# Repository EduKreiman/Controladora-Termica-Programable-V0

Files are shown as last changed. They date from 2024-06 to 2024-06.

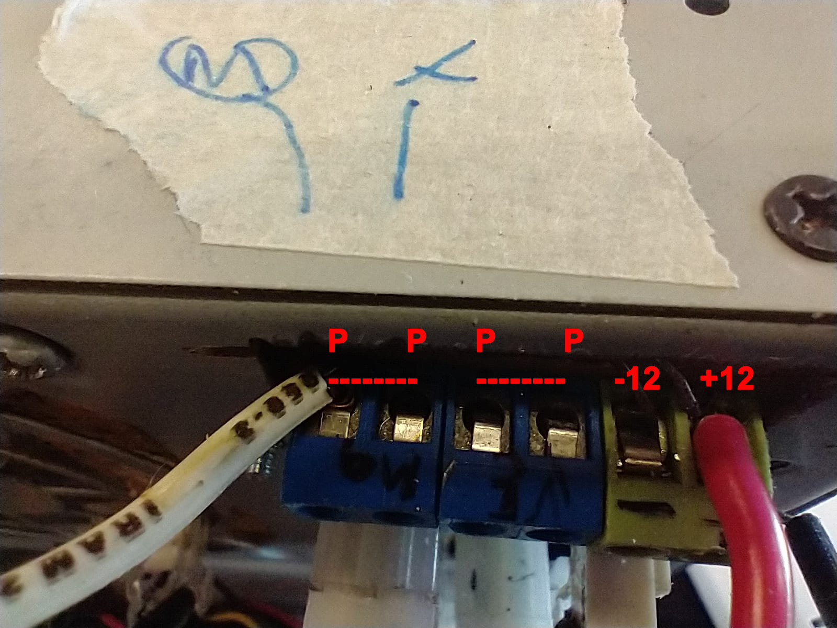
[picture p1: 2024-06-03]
Version03/hardware/conecciones bornera.jpg

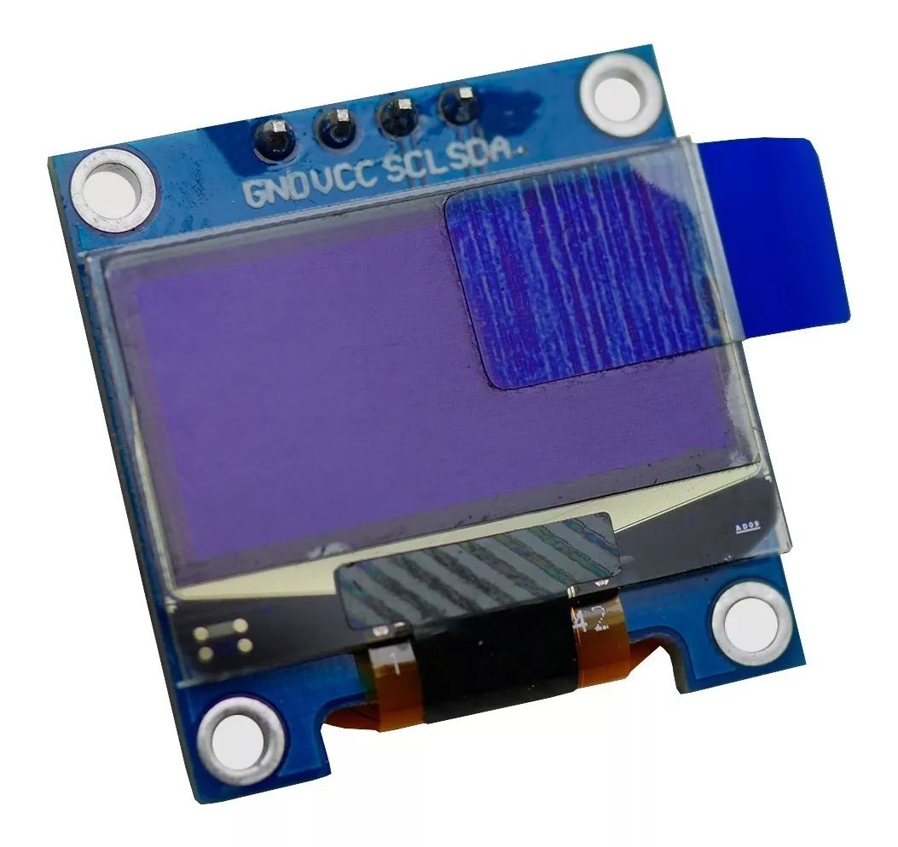
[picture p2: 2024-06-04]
Version03/hardware/display oled 1330 lado cristal.jpg

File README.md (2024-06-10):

En este repositorio se encuentran las descripciones de los circuitos necesarios para el ensamblado de una Controladora Térmica Programable (CTP), así como los scripts para su funcionamiento.

Las CTPs pueden ser utilizadas para dirigir ciclos térmicos diarios y el fotoperiodo dentro de una incubadora térmica, así como tambíen pueden establecer rampas térmicas para ensayos de temperatura crítica (CTmin y CTmax). Todas las funciones estan contenidas en un microcontrolador Arduino UNO.
Fueron construidas inicialmente para el Laboratorio de Ecofisiología de Insectos (IBBEA-CONICET-UBA), para experimentos con el objetivo de asestar el efecto fluctuación térmica sobre diferentes variables fisiológicas en insectos.

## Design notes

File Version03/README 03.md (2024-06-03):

VERSION 03 AUTONOMO-CONFIGURABLE OLED: El sistema esta contenido en un microcontrolador Arduino UNO. El funcionamiento es autónomo y continuo, repitiendo un programa termico seleccionado, entre los que están rampas térmicas ascendentes y descendentes, temperaturas constantes y el ciclo dirario de Parton&Logan, 1980. Asimismo controla simulación del ciclo de fotoperiodo diario cargando la hora de amanecer y anochecer en el sketch "parametror.ino"

La interfase de usuario consta de un display oled que junto con 3 pulsadores y un selector rotativo permiten a travez de menues sucesivos configurar todas las variables y seleccionar las rutinas termicas y el fotoperiodo.
  
Asimismo,un par de leds rojo y verde que indican el estado de enfriamiento o calentamiento respectivamente, y un tercer led que pulsa al ritmo de cada lectura de temperatura como indicador de funcionamiento correcto. La llave on/off de la fuente de alimentacion habilita el funcionamiento del equipo.

Un reloj interno (RTC), con batería de 10 años de duración, entrega el input para el cálculo de la ecuación para el ciclo diario. Esto le permite al sistema soportar interrupciones de alimentación, ya que el ciclo se reinicia en según la hora del reloj interno. Usa un sensor de temperatura Dallas Temperature (o Maxim Systems) Modelo 18b20, cuya lectura (Ti) es comparada con la temperatura de calculo para cada instante (Tcal). El signo de Ti-Tcal dispara la rutina frio/calor, activando la rama correspondiente del puente-H según la rutina seleccionada. El valor de ancho de pulso (PWM) que recibe el puente-H es función del módulo de Ti-Tcal, corregida por la rutina PID (Proporcional, Integral, Derivada).

Esta versión utiliza un puente H industrial de calidad automotriz con sistemas embebidos de proteccion termica e inversion de polaridad. 
se incluye en esta version un control de corriente / potencia entregada a la placa peltier para reducir el efecto Joule en la fase de enfriamiento. este se control se realiza con un modulo sensor de corriente por efecto Hall.

El control de la temperatura se logra a través de una placa peltier, tanto para el ciclo de calor como el ciclo de enfriamiento.

Referencias: Parton, W. J., & Logan, J. A. (1981). A model for diurnal variation in soil and air temperature. Agricultural Meteorology, 23, 205-216. https://doi.org/10.1016/0002-1571(81)90105-9

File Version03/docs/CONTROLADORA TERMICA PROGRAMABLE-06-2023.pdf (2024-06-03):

## CON

## Man

## Ope

1

0‐ Ini

Es

1‐ Set

2‐ Me

3‐ me

4‐ me

## NTROLADO

## nual de uso

## radores:

A | HUYE bo
B | ACEPTA‐
C | CAMBIA

Entra y Sale

Cambia dec

Cambia cícli

. Menúes o

icial: Siempre

ta pantalla m

teador: habilit

enú Modo/Pro

enú Temp | :
enú Foto | :
| P

CONTROLA
Diseño

## ORA TERMI

o:

otón: cíclico p

la opción o

BOTÓN p

BOTÓN p

ROTOR cam

e ‐>A

cimales ‐>B pu

icamente Cam

pantallas:

se vuelve a e

uestra: Las te

ta el ingreso a

ogs: seleccion

Temp. c

Temp. L

Circadia

: parametriza

: simula el fot

Parametriza am

ADOR TERMIC
o y Service 11

## CA PROGR

para entrar y s

o el campo mo

pulso mayor d

pulso corto ava

mbia dígitos e

Cambia N

ulso de 1 Sg.

mpos ‐>B pul

sta Pantalla/M

mperaturas M

La tempera

La temper

La diferenc

La hora ac

a los siguiente

na Programas

constante (Ter

Lineal (y=mx+

ano (modelo

T1 y T2 (Tem

operiodo regu

manecer y ano

CO PROGRA
1‐5472‐5201

## RAMABLE

https://drive.

salir del menú

ostrado en el

e 10 Sg cíclico

anza decimas

en display

Números ‐>R

lso mayor de

Menú. Pulsand

Min=T1 y Max

atura instantá

ratura Goal a

cia en Grados

ctual y el minu

es Menúes:

de comporta

rmostato)

+b)

o Parton/Loga

peraturas Mín

ulando la ilum

ochecer (foto

MABLE IEGE
email: ekre

google.com/file/d/1kt

ú en curso

display

o para pasar d

de grado o 5

Rotor

10 Sg

do A se pasa a

=T2 y el Modo

ánea del senso

lograr en ese

entre ambas

uto de disparo

miento térmic

n)

nima y Máxim

minación del i

operiodo) (Día

EBA: UBA &
iman@gmai

2iM5D_cFdyWlOmfSjx

de T1 a T2 o de

minutos de h

Acepta

al siguiente m

o o Programa

or del interior

instante.

o del autorese

co:

ma a desarrolla

nterior de la c

a y Noche)

CONICET
l.com

xJIYvbEPSNFpS/view?u

e Día a Noche

hora

‐>C=OK

menú

térmico.

r de la Cámara

et.

ar en el tiemp

cámara

sp=sharing

a.

o)

## Mem

Carac

Un gr
con u
Permi
los pa

Una r
arduin

Bloqu
Un m
librerí

Un dis
comp

Un pu

Un se
estab
reemp

Espec

Salida

Algori

Contr
comp

Contr

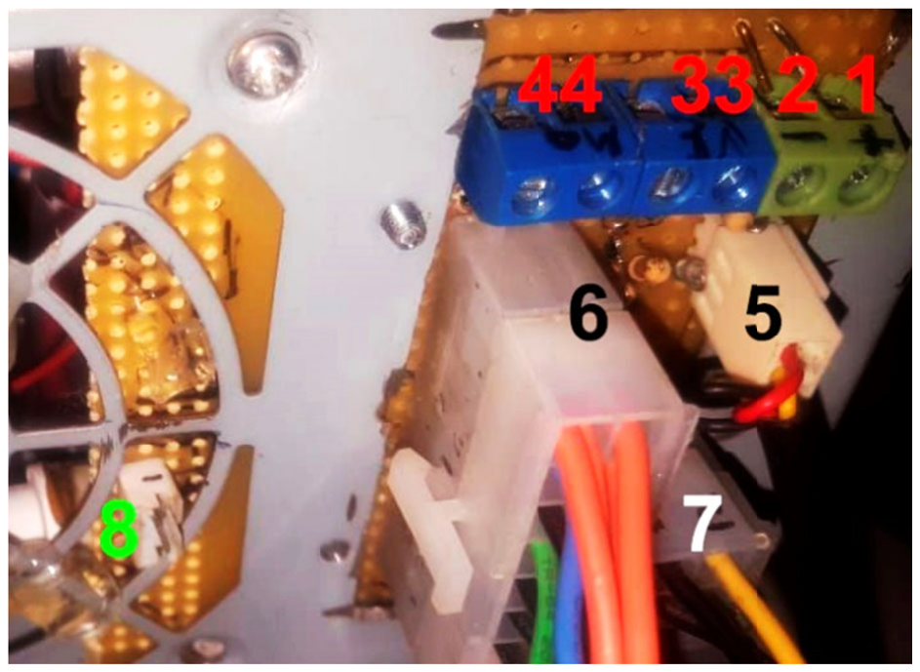
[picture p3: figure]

(drain
C, par

## moria Desc

cterísticas fu

upo de Menú
n reloj de tiem
iten el funcion
arámetros sete

utina tipo Wa
no y o inestab

ues funciona
icrocontrolad
ías para las fu

splay Oled B&
onen la Interf

uente H integr

ensor térmico
ilización del R
plazable rápid

cificaciones

DC pulsante

itmos para es

rol de histéres
ortamiento lla

rol electrónico

‐ gnd ) para a
ra alimentar b

CONTROLA

## criptiva

uncionales:

s cíclicos e int
mpo real (RTC
namiento con
eados y los ap

atchDog para A
bilidades.

ales:
or arduino Un
unciones más

N junto con u
fase Humana

rado de grado

integrado DS
RTC y lectura d
damente con e

Técnicas y C

a 600 Hz, var

tabilizar el co

sis, Rango de a
amado PARAM

o de PowerOn

alimentar Led
batería de data

ADOR TERMIC

tuitivos con so
C) con batería
ntinuo aun con
plica a la hora

Auto Reset ca

nO programad
complejas.

un encoder ro

o automotriz p

18b20 conect
de la tempera
enchufes está

onecciones:

iable por anch

mportamient

acción y Pode
METROR.INO

desde el mic

de fotoperio
alogger y otro

1‐5472‐5201

olo 5 operado
de 10 años de
n cortes de en
de actualizad

ada 10 minuto

do en C++ (ard

otativo con bo

para modulac

tado por I2C d
tura ambient
ándar.

ho de pulso‐ P

to y evitar osc

er relativo ent

roprocesador

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
odo. Más Salid
os

ores físicos pa
e duración y u
nergía, dado q
da para contin

os que previen

duino IDE) ori

oton pulsador

ión de poder.

de 0,20°C de p
al Una fuente

PWM (pulse w

ilaciones de la

re frío y calor

‐2 Salida 12V
owerOn)

‐33 Salida PW
1.5 volts a 15 A

Conector pola

molex 24 pins

molex 4pins i

‐Salida 12VDC

da 5VDC perm

ra todos los p
una memoria S
que al reiniciar
nuar la función

ne la saturació

entado a obje

y 2 pulsadore

precisión Un se
de alimentac

with modulatio

a temperatura

en un archivo

VDC para alime

WM alimentac
Amperes. (en

arizado a Sond

s input fuente

nput +12Vdc

C controlada p

manente stand

parámetros; ju
Sram (no volá
r lee de la me
n establecida

ón de memori

etos Un grupo

es adicionales

ensor térmico
ción de PC,

on)

a.

o de ajuste de

entar ventilad

ción placa Pelt
Frio ‐>> +4

da 18b20

por MosFet .

dBy .a conecto

unto
átil).
moria

ia del

o de

o para

dores

tier=
‐ 3)

or usb‐

| CONTROLA DOR TERMIC
‐5472‐5201

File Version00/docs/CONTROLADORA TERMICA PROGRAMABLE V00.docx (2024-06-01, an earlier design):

CONTROLADORA TÉRMICA PROGRAMABLE

Versión 00

Memoria Descriptiva

Características funcionales:

Esta versión 00 es Autónoma,, la selección y activación de la rutina de control térmico requiere modificar el archivo Parametror.ino y volver a subir el archivo compilado a la placa Arduino UNO con el software Arduino IDE, incluido en el repositorio GIT.

Un grupo de rutinas térmicas junto con un reloj de tiempo real (RTC) con batería de 10 años de duración y una memoria Sram (no volátil). Permiten el funcionamiento continuo aun con cortes de energía, dado que al reiniciar lee de la memoria los parámetros seteados y los aplica a la hora de actualizada para continuar la rutina establecida .

También el controla el fotoperiodo simulado dentro de la cámara encendiendo y apagando una tira de leds blancos siguiendo el ritmo circadiano.

Una rutina tipo WatchDog para Auto Reset cada 10 minutos que previene la saturación de memoria del arduino y o inestabilidades.

Las interfaces con el operador:

Interfaz Autónoma con un conjunto de led de colores que indican el pulso de lecturas y también la rutina térmica que está corriendo.

Interfaz Gráfica El paquete de software Control_Monitoreo.pde corriendo en processing y conectado por puerto serie, muestra la curva temporal de temperatura dela rutina activa, arroja el estado instantáneo del software y la cámara Hora y temperatura instantánea y calculada

Asímismo graba un archivo txt histórico a modo de datalogger que guarda en el disco duro de la PC.

Si el equipo se conecta a un sketch de processing también provisto se puede monitorear la curva circadiana la temperatura instantánea las temperaturas seteadas y demás parámetros

Este paquete adicional tiene incorporada las funciones para cambio de rutinas para ser usadas en la versión 01 de la CTP.

Consideraciones

Calibración de sensores: El ajuste de la lectura de los sensores con adjSensor es importante para obtener datos precisos.

Manejo de eventos: El uso de pulsadores físicos y comandos serie permite un control flexible del sistema.

Robustez: La inclusión de un reset automático cada 15 minutos ayuda a prevenir bloqueos del sistema.

Bloques funcionales del Harware::

Un microcontrolador arduino UnO programado en C++ (arduino IDE) orientado a objetos

Un grupo de librerías para las funciones más complejas.

Un display Oled B&N junto con un encoder rotativo con boton pulsador y 2 pulsadores adicionales componen la Interfase Humana

Un puente H integrado de grado automotriz para modulación de poder.

Un sensor térmico integrado DS18b20 conectado por I2C de 0,20ºC de precisión

Un sensor térmico para estabilización del RTC y lectura de la temperatura ambiental

Una fuente de alimentación de PC, reemplazable rápidamente con enchufes Molex estándar.

ANALIZSIS del PROGRAMA CTP

Este código combina múltiples tareas de monitoreo, control y comunicación para gestionar un sistema de temperatura, ajustando configuraciones y reaccionando a eventos en tiempo real.

El programa de Arduino se encarga de monitorear y controlar sensores de temperatura y un dispositivo de calefacción y/o refrigeración con celdas Peltier.

## Estructura General

1. **Inicialización y Lectura de Sensores**:

- La función `loop()` se repite continuamente y comienza por llamar a `avisala()`y activa un pin (`pinTCrict`) por un breve período para realizar una señalización.

- Se desactiva un flag (`test = false`) y se inicializan variables (`Suma` y `SumaDisip`) para almacenar sumas acumuladas de lecturas de temperatura.

2. **Medición de Temperaturas**:

- Se toman 5 mediciones de temperatura usando 2 sensores DS18B distintos (referidos como `tempActual` y `TempDisip`). - Se acumulan las lecturas y luego se promedian.

- `tempActual` es la temperatura de una cámara específica y `TempDisip` la temperatura del disipador para evaluar el salto térmico del Peltier.

- Se realizan ajustes a las lecturas de temperatura (`adjSensor` se suma a las lecturas). Para corregir el desvío de lectura obtenido en la calibración de las sondas sensoras.

3. **Manejo de Datos de Tiempo**:

- Se obtiene la hora actual usando un módulo RTC (`rtc.now()`).

- Se lee la temperatura del RTC y se realiza un seguimiento del tiempo para determinar el reinicio periódico del sistema. - **Reinicio del Sistema**: Realiza un reinicio automático si se detecta un bloqueo o pasa un tiempo específico.

4. **Comparación y Almacenamiento de Temperaturas**:

- Si las temperaturas actuales difieren de las anteriores (`tempAnt` y `tempDisAnt`), se actualizan las variables y se incrementa el contador de lecturas (`nLectu`).

5. **Lectura de Entradas y Gestión de Eventos**:

- Se leen estados de varios pines (botones o eventos).

- Si se presiona un botón de evento (`E`), se activa un buzzer y se alterna el estado de `test`.para esteo durante el desroollo del programa.

6. **Recepción de Datos por Serial**:

- El sistema escucha en el puerto serie (`Serial.available() > 0`) y responde a comandos específicos recibidos:

- **Comando '4'**: Realiza una serie de señales y lee varios valores desde el puerto serie (`T1`, `T2`, `nModo`, `nEvento`, `s3`, `s4`, `s5`).

- **Comando '2'**: Inicia el sistema, activando un optoacoplador y el buzzer.

- **Comando '5'**: Ajusta variables específicas (`T1`, `T2`, `nModo`, `nEvento`, `s3`, `s4`, `s5`).

- **Comando '7'**: Ajusta la hora del RTC leyendo valores específicos desde el puerto serie.

- **Comando '9'**: Realiza un reinicio del sistema y guarda datos críticos en memoria antes de reiniciar.

7. **Control de Tareas y Estado**:

- La función `rutMODO()` gestiona modos (rutinas térmicas) de operación del sistema.

- `pseudoPID_log()` y `TERMOSTAT()` se usan para el control de temperatura basado en un PID (Proporcional-Integral-Derivativo) simplificado.

8. **Reinicio Automático**:

- Se deshabilita el watchdog timer (`wdt_disable()`) y se verifica si ha pasado suficiente tiempo (15 minutos) para realizar un reinicio automático del sistema., Para prevenir rebase de memoria y otras irregularidades aleatorias.

### Funciones y Operaciones Clave

- **Lectura de Temperaturas**: Usa sensores DS18B20 para leer y promediar temperaturas.

- **Comunicación Serie**: Escucha y responde a comandos específicos recibidos por el puerto serie.

- **Control de Estados y Eventos**: Gestiona entradas digitales y eventos, incluyendo ajustes de tiempo y variables críticas.

- **Control de Temperatura**: Utiliza un sistema de control que incluye un PID para mantener la temperatura deseada.

Descripción general

Este programa de Arduino tiene varias funcionalidades relacionadas con la lectura de sensores de temperatura, la gestión de eventos y el manejo de comandos recibidos a través del puerto serie. Se utiliza un sensor de temperatura DS18B20 y un módulo RTC (reloj en tiempo real) para obtener la hora actual. Además, el programa puede recibir y procesar comandos desde un entorno externo, como Processing.

Análisis detallado del código

1. Inicialización y Configuración

Variables y objetos: El código asume la existencia de variables globales y objetos para manejar los sensores y el RTC.

Sensores de temperatura: Se utiliza un sensor DS18B20 para medir la temperatura en diferentes puntos.

2. Función loop()

La función loop() es el núcleo del programa y se ejecuta continuamente. Aquí se realizan las siguientes acciones:

Aviso inicial y manipulación de pines:

avisala();

digitalWrite(pinTCrict, HIGH);

digitalWrite(pinTCrict, LOW);

Lectura de sensores:

Se inicializan variables para la suma de temperaturas.

Se toman cinco mediciones de temperatura y se calculan promedios.

Se realiza la compensación de las temperaturas medidas utilizando un coeficiente de calibración (adjSensor).

Se lee la temperatura actual (tempActual) y la temperatura del disipador (TempDisip).

Obtención de la hora actual del RTC:

DateTime now = rtc.now();

Lectura de temperatura del RTC:

TempAMBIENT = rtc.getTemperature();

Envío de datos:

Si hay un cambio en las temperaturas leídas, se actualizan y se envían los datos. Ia seral al programa de monitoreo grafico que corre en prossesing.

Lectura de estados de pulsadores:

Se leen los estados de varios pines que representan pulsadores (pinSTART, pinABORT, pinEVENTO).

Si se detecta un evento, se activa un buzzer y se alterna el estado de la variable test.

Procesamiento de comandos recibidos por el puerto serie:

Se verifica si hay datos disponibles en el puerto serie.

Según el comando recibido (representado por dataIN), se ejecutan diferentes acciones:

Comando '4': Realiza pruebas y emite señales con el buzzer.

Se activa y desactiva pinTCrict varias veces.

Se emiten sonidos con el buzzer.

Se leen y procesan varios valores de temperatura.

Comando '2': Inicia una operación (START).

Se activa un relé (pinOPTOCUPLER).

Se emiten sonidos con el buzzer para indicar el inicio.

Comando '5': Configura variables (DATASET).

Se leen varias configuraciones enviadas por el puerto serie y se almacenan en variables.

Se graban estos valores en memoria.

Comando '7': Ajusta la hora del RTC según los datos recibidos.

Comando '9': Realiza un reset del sistema.

Se activa pinTCrict durante un periodo prolongado.

Se emiten sonidos con el buzzer.

Se realiza un reinicio del sistema.

Lógica del termostato y control del sistema:

Se ejecuta una función para manejar modos o rutinas termicas (rutMODO()).

Se realiza un control de temperatura (TERMOSTAT(Tinstant, tempActual, Tmargen)).

Se maneja un PID lógico (pseudoPID_log()).

Consideraciones

Calibración de sensores: El ajuste de la lectura de los sensores con adjSensor es importante para obtener datos precisos.

Manejo de eventos: El uso de pulsadores físicos y comandos serie permite un control flexible del sistema.

Robustez: La inclusión de un reset automático cada 15 minutos ayuda a prevenir bloqueos del sistema.

Especificaciones Técnicas:

Salida DC pulsante a 600 Hz, variable por ancho de pulso- PWM (pulse with modulation)

Algoritmos para estabilizar el comportamiento y evitar oscilaciones de la temperatura.

Control de histéresis, Rango de acción y Poder relativo entre frío y calor en un archivo de ajuste de comportamiento llamado PARAMETROR.INO

Control electrónico de PowerOn de fuente desde el microprocesador

Salida PWM alimentación placa Peltier= 11.5 volts a 15 Amperes.

Salida 12VDC controlada por MosFet para alimentar Led de fotoperiodo en cámara.

Salida 12VDC para alimentar ventiladores (on con PowerOn)

Salida 5VDC conector usb-C, para alimentar batería de datalogger, ,etc .

Salida 5VDC permanente standBy para alimentar microprocesador.

El archivo Parametror.ino

amanecer 8hs01 anochecer 20hs01

Eduardo Kreiman WS= +54 911 5472 5201 ekreiman@gmail.com abril 2023 # 5

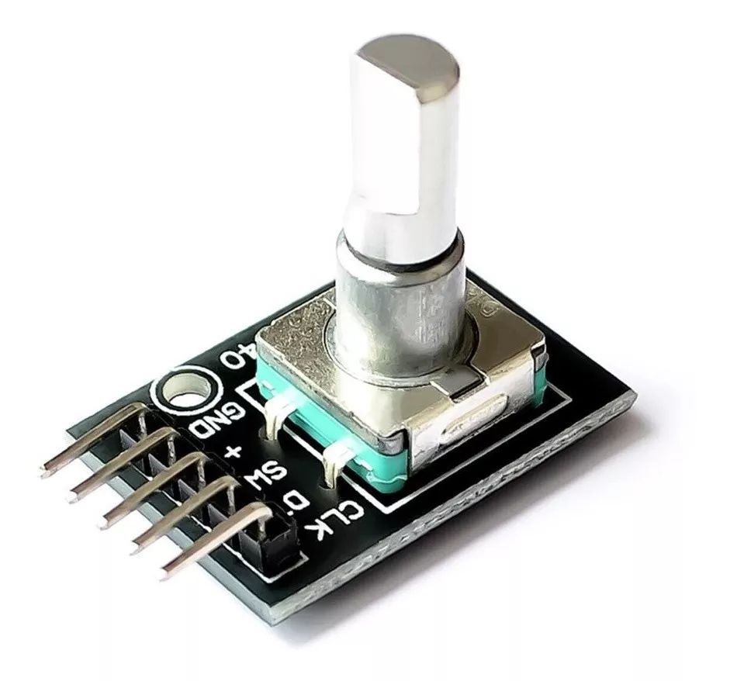
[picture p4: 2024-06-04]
Version03/hardware/encoder rotativo.jpg

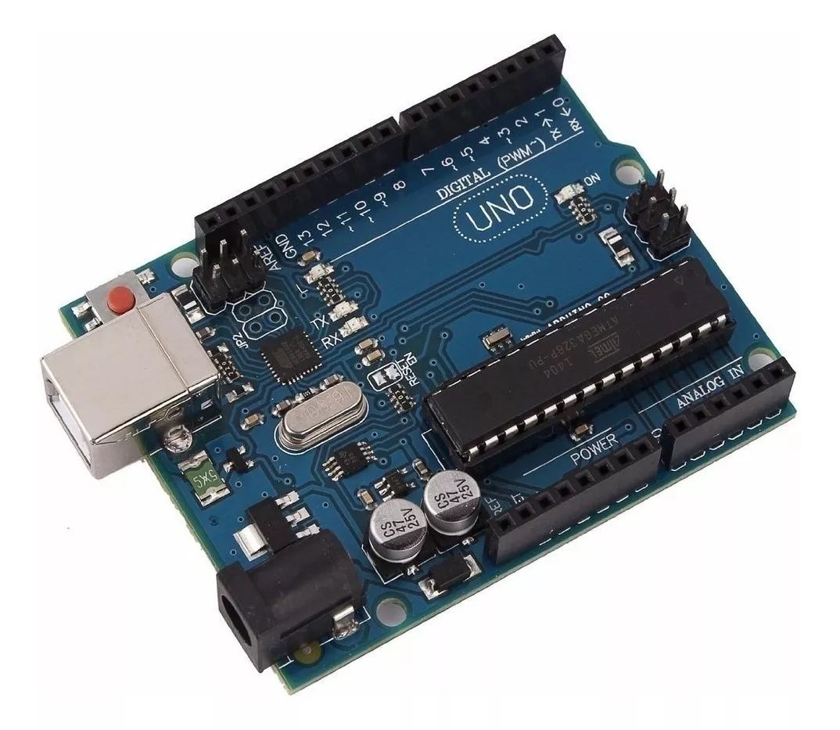
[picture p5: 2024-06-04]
Version03/hardware/Arduino UNO.jpg

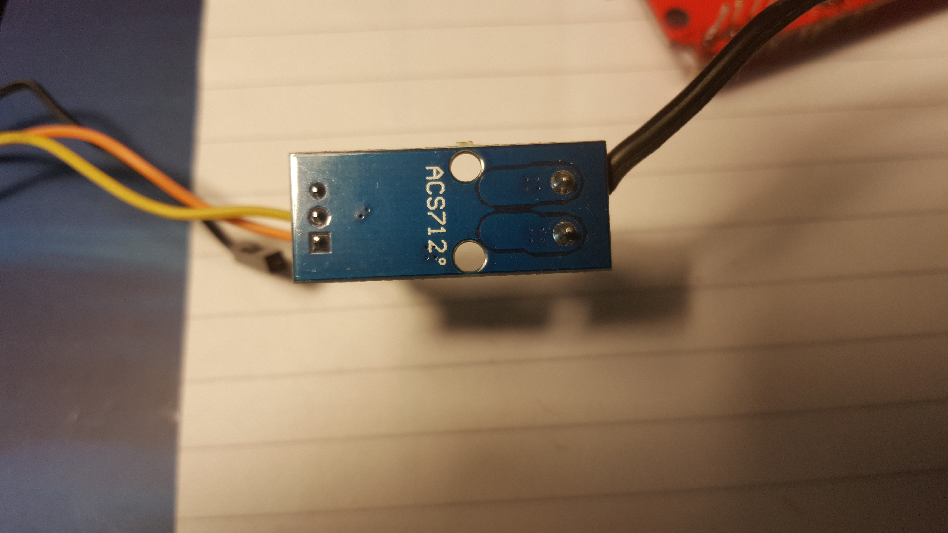
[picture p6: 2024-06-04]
Version03/hardware/ACS712 current-sensor-01.jpg

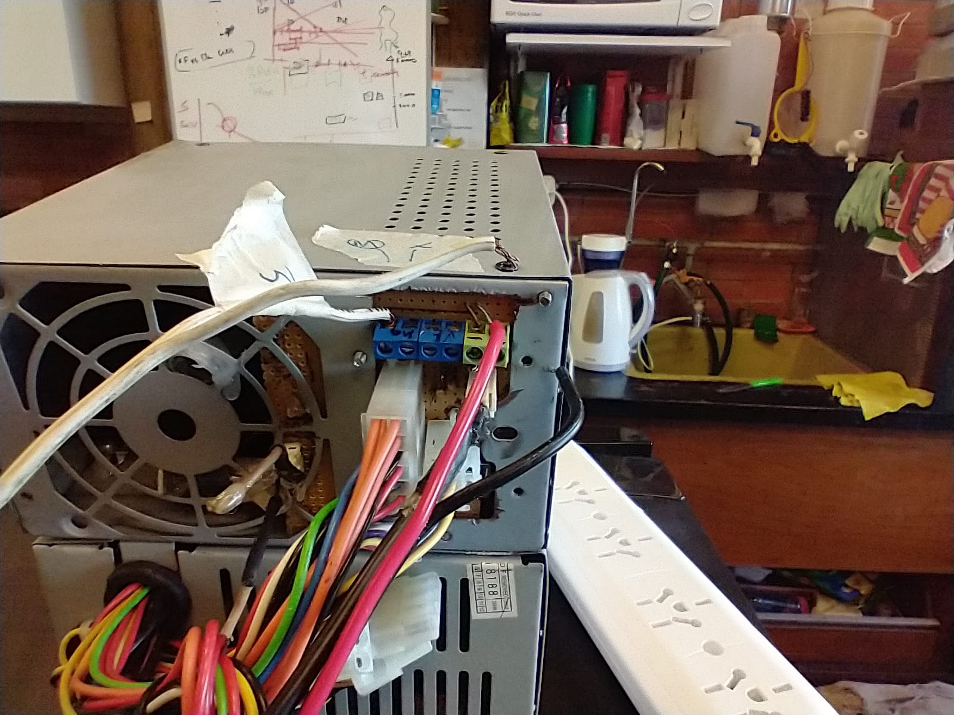
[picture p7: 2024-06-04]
Version03/hardware/conecciones bornera 01.jpg

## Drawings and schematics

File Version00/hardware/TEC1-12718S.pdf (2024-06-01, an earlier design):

# Peltier-Element TEC 1 ñ 12718 S

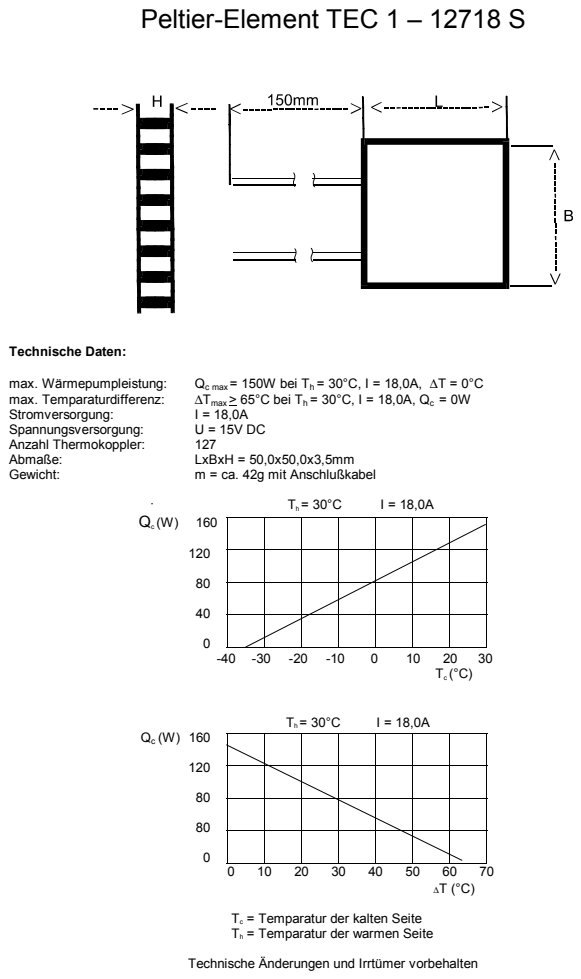
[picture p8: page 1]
Technische Daten:; max. W‰rmepumpleistung:; Qc max = 150W bei Th = 30°C, I = 18,0A, ∆T = 0°C; max. Temparaturdifferenz:; ∆Tmax > 65°C bei Th = 30°C, I = 18,0A, Qc = 0W; Stromversorgung:; Spannungsversorgung:; Anzahl Thermokoppler:; Abmafle:; LxBxH = 50,0x50,0x3,5mm; Gewicht:; m = ca. 42g mit Anschluflkabel

Tc = Temparatur der kalten Seite
Th = Temparatur der warmen Seite

Technische ƒnderungen und Irrt¸mer vorbehalten

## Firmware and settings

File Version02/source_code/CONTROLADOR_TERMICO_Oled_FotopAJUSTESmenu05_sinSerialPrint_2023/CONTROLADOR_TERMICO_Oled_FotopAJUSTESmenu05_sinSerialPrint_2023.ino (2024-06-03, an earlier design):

#include <Wire.h>


/*CONTROLADOR_TERMICO_CIRCADIANO_ENCODER_OLED                        19-03-2023
  CONTROLADOR_TERMICO_Oled_FotopAJUSTESmenu05_sinSerialPrint_2023

diseño y programacion EDUARDO KREIMAN
consultas y asesorias 054-011-5472-5201
ekreiman@gmail.com

IMPORTANTE: CARGAR TODAS LAS LIBRERIAS ANTES DE SUBIR EL SKETCH A LA PLACA

LA RUTINA: Parametror();//AJUSTESySETEOS(); CONTROLA LOS PARAMETROS INICIALES
LA LINEA 420 INICIALIZA EL RTC 
-------------------------------------------------------------------------------------------------------

oled.setFont(System5x7);
*/

/*
 pasta térmica 
 Un exceso de pasta térmica empeorará el rendimiento térmico del sistema. 
 Lo ideal «menos es más» es una capa de pasta térmica casi transparente.

 TempCamara Ti= 18.20ºC   Tcal 17.02ºC   DELTA Goal/Camara 1.17ºC    Tmin set 16.10ºC     TempAire exterior= 22.25ºC SaltoTº Int/Ext= -4.05ºC 
 
fuente 11.03v out pwm255 10.45v    Serial.voltimetro=4.86v / 5.36v

127 08---> 10v45  4.71 A

127 05--->fuente 11.03v 10v45  2.71 A ----FUXIN  TEC1-127 05fx  dbc 2013/10--https://www.airecontrol.com.ar/tec1---12705fx.html--
          
          fuente 11.03v  6v77  1.97 A r=27ohms   out pwm255   Serial.voltimetro=4.77v    24-04-2023

cambio peltier 14-04-2023 camara frigobar gris

REPOSITORIO:    Eduarq NUBE  e01kreiman@gmail.com
https://docs.google.com/document/d/1vcTVYxaLnhMcUdjbMWwd1TrjF9DZqiPkKovk91h1lXA/edit?usp=share_link

Compartir "ControladoraTérmica"    https://drive.google.com/drive/folders/1YoPP9A5MYGMUdpDPp951JbSK1InDlZAB?usp=share_link

/*
/********************************************************************/

#include "DS18B20Events.h"
#define ONE_WIRE_BUS 12
// Setup a oneWire instance to communicate with any OneWire devices(not just Maxim/Dallas temperature ICs)
OneWire oneWire(ONE_WIRE_BUS);

DallasTemperature dallasTemperature(&oneWire);// Init DallasTemperature

DS18B20Events thermometer(0);//Init thermometer with index 0 (default)

#include "SSD1306Ascii.h"
#include "SSD1306AsciiAvrI2c.h"

// 0X3C+SA0 - 0x3C or 0x3D
#define I2C_ADDRESS 0x3C

#define RST_PIN -1 // Define proper RST_PIN if required.

SSD1306AsciiAvrI2c oled;  //DISPLAY MONOCROMATICO 128 X 64 PIXELS

float volatile Tactual = -12.34;
//-----------------------------------------------

bool test = false;  //boolean test=true; PARA DESARROLLO MONITOREADO se habilita en PARAMETROR
bool test01 = false;  //boolean test=true; PARA DESARROLLO MONITOREADO de modos se habilita en PARAMETROR

#include <AT24CX.h>  //BIB  memoriA eeprom en modulo RTC DS3231
AT24C32 EepromRTC;   //Declarar EepromRTC  clase con tamaño de página predefinido

//MODELO DE datos a guadar en EepromRTC
                                          /*
                                                  // byte variable_byte=128;
                                                  int variable_int = 3000;
                                                  // long variable_long=48300011;
                                                  float variable_float = 3.14;
                                                  char cadena[30] = "time= hh:mm:ss";
                                          */
int aAT24;
float bAT24;
float cAT24;
float dAT24;
float eAT24;
float fAT24;
float gAT24;
char cadenaTiempo;
//char cadena2[30];
//char cadena[30] = "time= hh:mm:ss";
//datos a guadar en EepromRTC
float  MTimeStart;
bool MpasoSoak;
float HcRTC = 0.123456789;// fotoperiodo 
float hcOn  = 0.123456789;// fotoperiodo   
float hcOff = 0.123456789;//fotoperiodo 
float XhcOn = 0.123456;//    fotoperiodo 
float hhSX  = 0.123456789;// fotoperiodo 

const int Sw3 = A1;  // BOTON SwB
const int Sw2 = A2;  // BOTON SwA

//sensors.getTempC(DeviceAddress);// //-> Sensor 3 : 0x28, 0x1A, 0x37, 0x76, 0xE0, 0x01, 0x3C, 0xE0 // -------->ETIQUETA negra termocontraible

#include "EasyBuzzer.h"
const int BUZZER = A0;  //buzzer  con led azul en paralelo usa pasivo con trNPN buffer rutina de tono 450Hz  libreria easyBuzzer
unsigned int frequency = 400;
unsigned int onDuration = 500;
unsigned int offDuration = 500;
unsigned int beeps = 5;
unsigned int pauseDuration = 500;
unsigned int cycles = 10;


// protocolo de comunicacion I2C Arduino UNO, NANO reserva por default -> SDA = A4 y SCL = A5 NANO
//#define SCL 5  protocolo de comunicacion I2C   The compiler will replace any mention of scl with the value 5 at compile time.
//#define SDA 4  protocolo de comunicacion I2C   The compiler will replace any mention of scl with the value 4 at compile time.

#include <Encoder.h>
// Change these two numbers to the pins connected to your encoder.
//   avoid using pins with LEDs attached
//   Best Performance: both pins have interrupt capability
//   Good Performance: only the first pin has interrupt capability
//   Low Performance:  neither pin has interrupt capability
//NANO  PIN con habilidad de INTERRUPT= D3 y D2
//              DT, CLK
// clase   objeto
   Encoder myEnc(3,2);// PINES DIGITALES CON INTERRUPCION INVIERTE EL ORDEN INVIERTE SENTIDO DE lectura del GIRO
//int contador = 0;
long oldPosition = -999;
#define boton 4  // BOTON DEL Encoder ROTATIVO
#define pinFOTOPERIODO 11

#include <RTClib.h>  // ---paraRTC real clock time    https://adafruit.github.io/RTClib/html/class_r_t_c___d_s3231.html
//   clase objeto
RTC_DS3231 rtc;      // Declaramos un RTC DS3231
//#include <DS3231.h>// libreria de arduino parece mas liviana   https://www.arduino.cc/reference/en/libraries/ds3231/
//                                                               https://github.com/NorthernWidget/DS3231
//The Library assumes that the DS3231 has an I2C address of 0x68.
// is a splice of Ayars' (http://hacks.ayars.org/2011/04/ds3231-real-time-clock.html) and Jeelabs/Ladyada's

//#include <MemoryFree.h>//usada solo en desarrollo del soft

#include <avr/wdt.h>  //watch-dog-Timer, esta librería  dispara una interrupcion que llama una funcion  cuando se acaba el tiempo
//***************************************************** DESCOMENTAR para activar AUTO-RESET
//                  void(* resetFunc) (void) = 0; //declare reset function @ address 0   enviado por referencia de C++
//***************************************************** DESCOMENTAR  para activar AUTO-RESET
/*para restablecer la placa, se implementa un ciclo corto,(15 milisegundos) 	WDTO_15MS				
                                      cuando el tiempo de espera expira, el sistema se reinicia									
                                      al llamar a la funcion      software_Reboot     reiniciando la placa a los 15 ms.
                                      Processing recupera la coneccion luego del reset

                                        void software_Reboot()				
                                          {			
                                            wdt_enable(WDTO_15MS);        //watchdogTIMER  buenisimo Timer por INTERRUPCION
                                                                          //usarlo para time en soak o para tiempo entre de lecturas	
                                              while(1)		
                                              {		
                                              }		
                                          }			
                                      */



/*
PUENTE H 
DRIVER MONSTER :--- VNH2SP30 full-bridge motor driver
MonsterMotor uses two VNH2SP30 high-current full-bridge motor drivers.

The motor variable in each function should be either a 0 or a 1.
pwm in the motorGo function should be a value between 0 and 255.

5  pwm in the motorGo function should be a value between 0 and 255.
7  variable in each   function should be either a 0 or a 1.
8  variable in each   function should be either a 0 or a 1.
*/

#define BRAKEVCC 0
#define CW 1
#define CCW 2
#define BRAKEGND 3
#define CS_THRESHOLD 100
/*  
motor A
Pines 5 y 6 son PWM.
Pines 4 y 9 controlan el giro del primer motor.

motor B
Pines 5 y 6 son PWM.
Pines 7 y 8 controlan el giro del segundo motor.

para cada chip
            6 ENA/DIAGA Status of high side and low side switches A; open drain output
5 INA Clockwise input
8 PWM PWM input
          9 CS Output of current sense
11 INB Counter clockwise input
          10 ENB/DIAGB Status of high side and low side switches B; open drain output

tabla de Verdad

INA  INB  1/2puente-A    1/2puente-B     MODO 
1     1        H             H           freno en  alta
      0                      L           giro horario

0     1        L             H           giro ant-horario
      0                      L           freno en  baja GND


MONSTER MOTO de Sparkfun. 
https://github.com/sparkfun/Monster_Moto_Shield/tree/Hv12Fv10
Voltaje máximo: 16V
Corriente pico máxima: 30 A
      con hasta 6A, los chips apenas se calentarán perceptiblemente.
Corriente Continua Práctica: 14 A
Detección de corriente disponible para pin analógico Arduino
resistencia MOSFET: 19 mΩ (por pierna)
Frecuencia máxima PWM: 20 kHz
Apagado térmico
Apagado por subtensión y sobretensión

VNH2SP30 pin definitions
 xxx[0] controls '1' outputs
 xxx[1] controls '2' outputs 
 */
//define array para 2 puentes H
int inApin[2] = { 7, 4 };  //  INA: Clockwise input          sentido horario      FRIO
int inBpin[2] = { 8, 9 };  //  INB: Counter-clockwise input  sentido anti-horario CALOR
int pwmpin[2] = { 5, 6 };  //  PWM input

//estos pines no estaran conectados
int cspin[2] = { 2, 3 };  //    CS: Current sense ANALOG input
int enpin[2] = { 0, 1 };  //    EN: Status of switches output (Analog pin)

//int statpin = 13;// led onboard

const int pinOPTOCUPLER = 9;  // Led OPTOCUPLER cable verde de fuente
const int pinPOTE = A3;       // pote  usar pin analog read MONITOREAR TENSION PUENTE H
int horaAnt = 0;              //hora de inicio del setup para resetear por software cada N horas
int minutAnt = 0;             //hora de inicio del setup para resetear por software cada N horas

unsigned long volatile tiempoLectura = 0;   // Tiempo en que se presionó el botón
unsigned long volatile duracionLectura = 0; // D

//boolean LEDState = LOW;       //APAGA el LED
//boolean status = LOW;         //Estado del led
//char dataIN;                  // Data recibida desde el Puerto serial
//char val; // Data recibida desde el Puerto serial
String ENTROPIA = "EstadoBombaTermica";  //"COOLING"

float tempActual = 0.1;
int temp;  // Variable sensor de temperatura
//float RawValue = 0.1;
//float value;
float T1 = 0.01;      //tempArranque -GOAL->  temp de inicio         --carga inicial para desarrollo   
float T2 = 0.01;      // tempSET -META->  temp a llegar en rampa ---carga inicial para desarrollo
float Tmargen = 0.01;  //histeresis de termostato, Tmargen  pseudo PID viene de slider s5
int PwFrio = 0;
int PwHot = 0;

//float deltaTemp = 0.1;      // instantanea para display
float tempAMBIENT = 0;      //rtc
float tempAMBanterior = 0;  //rtc
float tempAnt = 0;          //almacenar la temperatura en una variable  del tipo float.
//float tempDisAnt = 0;
float tempTT = 0;  //variable local en rutina TERMOSTATO

//int nEvent = 0;         // contador de eventos
//int nLectu;             // contador de LECTURAS DE TEMPERATURA
bool LLegueT1 = false;  //   Flag DE CONTROL DEL TERMOSTATO

 
int nModo = 0; 

//char buf1[20];  //character array to save the output string into.
float s3 = 0;  //pid 
float s4 = 0;    //pid  valor %  rango 0 a 100
//float s5 = 0.15;  //pid Tmargen  multiplicar y dividir por 100 para recibir decimales
//float volatile Tinstant = 0;
float  Tinstant = 0;
//float sgCorrida = 0;

float Avance=0;
float TimeStart=0;
//unsigned long miliAhora = 0;
//unsigned long miliStart = 0;
bool pasoSoak=true; 
//unsigned long miliSoak = 0;
//unsigned long miliAvance = 0;
//4 minutos centesimales= 0.066666666; pendiente=  1/0.066666666= 15
float mRecta =0;   //0.000004167;   //0.25 / 60;    unidad second()  pendiente de la recta  m=1 grado cada 4 minutos

// second() 0 a 59 if second < 1 sumar 59 a la variable

int x = 0;
float incrementa=0.00;
float incrementador=0.1;
//Prototipos de las funciones para definirles el alcance *********************************
void TERMOSTAT(float _T1, float _T2, float _margen);  //Prototipo
void ENVIADATA();
void ENVIAstatus();
void pseudoPID_log();
void done();
//void enviaOLED();
void avisala();
void grabaMEM();  // guarda datos en memRTC
void leeMEM();    // lectura y presentacion y recupera datos en variables
void Voltimetro();

void motorGo(uint8_t motor, uint8_t direct, uint8_t pwm);

void leeStepper(int _Fila,int _Columna);
void leeStepper(int _Fila,int _Columna,int _S,bool _I);  //     0 a 7  , 0 a 239, 1 ó 2,  0 ó  1
void Parametror();//AJUSTESySETEOS();
void Aceptor();

void displayOLED(); //0  hoja principal default muestra estado y temp actual

void menuSeteador();//1

void menuModo();    //2 
             void rutMODO();       //rutinasMODO
             void Lineal();        //rutinasMODO
             void R_circadiano();  //rutinasMODO
             void LinealCTE();     //rutinasMODO
               //void R_TCritica();//rutinasMODO
               //void R_termos();  //rutinasMODO 

void menuTEMP();    //3  T1 Y T2

void menuFOTO();    //4  SUNSET Y SUNRISE

void fotoperiodo();// REGULA ILUMINACION DENTRO DE LA CAMARA  

void blinkFOTOPERIODO();//AVISO con luz INTERMITENTE EN CAMARA

//void software_Reboot();  // esta funcion se llama cada N horas  para evitar bloqueos. EN nano NO FUNCIONA SOLO SI SE CAMBIA EL BOOTLOADER CON UNO
void autoReset(); //Dado que la prueba de rampa tiene una duracion maxima de 90 /120 minutos se deshabilita para esta funcion el autoreset /o se lo setea en 120 minutos
void temperatureChanged(uint8_t index, float tempC);
float obtenerHoraCentesimal();
//Prototipos de las funciones para definirles el alcance *********************************



                    // https://www.electrodaddy.com/las-matematicas-en-arduino/
float hs = 0;  // uso en circadiano hora reloj format centecimal
float T_calActual = 0;
//float TempDisip = 0;
float incremento = 0;
float Suma = 0;
float SumaDisip = 0;
float aManecer = 8.00;    // hs= Srise  centecimal  dato
float aNochecer = 20.00;  // hs =S set  centecimal  dato
const float b = 0.8;      //=coef ajuste NOCHE
const float a = 1.5;      //=coef ajuste DIA
float tempMin = 16.00;    //activa Slider s1 // modo tropical VZ
float tempMax = 32.00;    //activa Slider s2 // modo tropical VZ
float deltaT = 0;
float T_aNoche = 0;
//----------
float m = 46.3;  //ecuacion de la recta
int b0 = 68;     //ecuacion de la recta
float delta;
float tension = 0;             // voltimetro
float adjSensor = 0;  //COEF DE CALIBRACION DEL SENSOR   tempActual linea 483  
int ajuste = 1;                // Bloquea solo 1 ajuste de hora por corrida para solicitar otro requiere pasar por reset que es automatico cada 15 minutos
float ajustambiental = -3.25;  // corretor de desvio del sensor de temperatura tempAMBIENT
int rstMin = 49;         // tiempo en minutos para disparar auto reset
int reinicio = 15;
int Mreinicio = 1;

int newPosition = 0;
float PosiDec =0.01; 
float oldtempActual = -0.01;

bool paso = false;
bool Seteador = false;
bool setFoto= false;//4
bool setTEMP= false;//3
bool setMODO=true;  //2
bool Bot = false;
bool acepta=true;

int LASTposition=0;
bool Decimal= false;
int contador = 0;
bool miniMenu=true;//circular entre T1 y T2
int tomas=5000;// Set min interval in milliseconds between 2 measurements. Default 10000 set in setup() method.

void setup() {  //oooooooooooooooooooooooooooooooooooooooooooooooooooooooooooooooooooooooooooooooooooooooooooooooooooooooooooooooooooooo
  //Serial.begin(19200);
  //asyncTask1.Start(); //avisala(); //conflicto con encoder ????
  //asyncTask2.Start();                         
                        
  DS18B20Events::setup(&dallasTemperature);  // Link DS18B20Events to DallasTemperature object  USA PASO DE VALORES POR REFERENCIA  ::  ?????
  DS18B20Events::setInterval(tomas);          // Set min interval in milliseconds between 2 measurements. Default 10000 set in setup() method.

  thermometer.onChange = temperatureChanged; // subscribe to temperature changed event

  oled.begin(&Adafruit128x64, I2C_ADDRESS);
  // Call oled.setI2cClock(frequency) to change from the default frequency.

  oled.setFont(Adafruit5x7);
  oled.clear();
 
  uint32_t m = micros();
  wdt_disable();  //siempre es bueno deshabilitarlo al comienzo
 // Serial.println(F("apago WDT"));

  // PULSADORES SELECTORES
  pinMode(Sw3, INPUT);           // pin ardu A1   pull down con resistencia 1K5 y FILTRO 100NF en PCB
  pinMode(Sw2, INPUT);           // pin ardu A2   pull down con resistencia 1K5 y FILTRO 100NF en PCB
  pinMode(boton, INPUT_PULLUP);  // pin del pulsador del Stepper rotatvo siempre UP
  pinMode(pinOPTOCUPLER, OUTPUT);
  pinMode(BUZZER, OUTPUT);
  pinMode(pinFOTOPERIODO, OUTPUT);
  
  //----------- Modulo RTC
 // Serial.println("modulo_RTC");
  if (!rtc.begin()) {  //--------------verifica el RTC conectado
  //  Serial.println("No_hay_modulo_RTC");
    while (1);  //espera un microsegundo
  }//--------------verifica el RTC conectado
      
          // Poner en hora solo la primera vez,con los valores de la fecha y la hora en que el sketch ha sido COMPILADO
        //  rtc.adjust(DateTime(F(__DATE__), F(__TIME__)));// Fijar a fecha y hora de COMPILACION el sketch // luego comentar y volver a cargar.
        //  reporte de error: no usar  este ajuste automatico
        //    https://enioea2hw.wordpress.com/2020/04/09/reloj-dual-con-rct3231-y-arduino/#more-4372
//----------- Modulo RTC

  DateTime now = rtc.now();  //toma datos del modulo RTC

  horaAnt = now.hour();     //hora de inicio del setup y control de reset cada N horas
  minutAnt = now.minute();  //minuto de inicio del setup y control de reset cada N minutos                        
                             //memoria EEPROM EN Mmodulo RTC  068 para EL RELOJ Y 057 para LA MEMORIA
  /*ASIGNA LA DIrECCION DEL MODULO ademas por Hard soldando A1 A2 A3  A GND=0   EN EL MODULO 0x+0x2+0x3 --> 0x1 +0x2 + 0x4	=0
                                                                     A VCC=1   EN EL MODULO x+x2+x3 -------> 1 + 2  +	 4	=7                            
   AT24C32(0x57);  //ASIGNA LA DIRECCION DEL MODULO de memoria EEPROM por soft
  // Search at [57]: FOUND!  con sketch     AT24CX_search_ICmem.ino
  */
Parametror();//AJUSTESySETEOS();// reemplaza a leeMeM en desarollo o seteo fijo

leeMEM();  // lectura y presentacion y recupera datos en variables

EasyBuzzer.setPin(14);
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
void loop() {
  tempAMBIENT = rtc.getTemperature();          // LEER TEMPERATURA DEL modulo RTC  DEVUELVE   Current temperature (float)

  tempAMBIENT = tempAMBIENT + ajustambiental;  // corrector de desvio del sensor de temperatura del moduloRTC
  
  thermometer.loop();                   // Mandatory to measure temperature and fire an event if needed
  
 tempActual = thermometer.getTempC();  // Get last measured tempC if needed.
 tempActual = tempActual + adjSensor; // corrector de desvio del sensor de temperatura DS18b20
            if (tempActual != oldtempActual) {
              oled.clear();
              oldtempActual = tempActual;
            }


//asyncTask1.Update(asyncTask2);//necesario llamar frecuentemente al método Update() funcion definida antes del setup
//asyncTask2.Update(asyncTask1);//coflicto ???


EasyBuzzer.update();  //Always call this function in the loop for EasyBuzzer to work. 

//Dado que la prueba de rampa tiene una duracion maxima de 90 /120 minutos se deshabilita para esta funcion el autoreset /o se lo setea en 120 minutos
if (nModo!=2){autoReset();	}//void software_Reboot()	{	// esta funcion resetea el arduino y se llama cada 2 horas  para evitar bloqueos.	
//Dado que la prueba de rampa tiene una duracion maxima de 90 /120 minutos se deshabilita para esta funcion el autoreset /o se lo setea en 120 minutos

Aceptor();// lee el pulsador del rotor (swC=OK) , cambia las variables  Bot (togle)  y acepta=true; 
          // Bot = digitalRead(boton);// si se pulsa  su valor va a BAJO == false 

displayOLED();// hoja default muestra estado y temp actual  muestra siempre             

fotoperiodo();//controla luz led en camara


//  SwA=Sw2  llama a menuSeteador que entra en un while y se CONTROLA con la variable bool Seteador--> si Seteado r== true entra en un while 
//               menuSeteador llamará las rutinas: 1progs/modos  2temp  3foto  NNno opcion    
if (digitalRead(Sw2) == HIGH) {  Seteador = !Seteador; avisala(); }// ---------->>>> entra y sale del  menuSeteador  ><<<<<<<<<<<---------   

// ooooooooooooooooooooooooo ooooooooooo  while de seteador
paso = false;// evita parpadeo de sobreimpresion del display
while (Seteador == true)  
                {   motorGo(0, 2, 0);//quita energia en puente H mientras setea
                   // atencion aqui    autoReset();//actualizado dentro del while 
   
                    if (digitalRead(Sw2) == HIGH) { Seteador = !Seteador; }// ---------->>>> entra y sale del seteador  con SwA><<<<<<<<<<<---------

                               leeMEM();

                    Aceptor();//lee el pulsador del rotor (swC=OK) , cambia la variable  Bot (togle)  y acepta=true;   
                    menuSeteador(); //----- void menuSeteador(){// 1-                      
  }  // oooooooooooooooooooooooooooooooooo cierra while de seteador

rutMODO();  //   llama a la funcion termica corespondiente para obtener      Tinstant para parametrizar LA FUNCION  termostato
pseudoPID_log();  // ajuste  PWM pseudoPID evalua delta(local) y setea PwHot y PwFrio
TERMOSTAT(Tinstant, tempActual, Tmargen);  // LLEVA LA PLACA A T1  Tinstant
//Serial.print(F("MemoryFree()= "));  Serial.println(freeMemory());
}

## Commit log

2024-04-04 Create circuito.md
    circuito en link y en txt para editar en Fritzing
2024-04-04 Add files via upload
    grafica de control de un dattaloger para verificar la respuesta térmica en el tiempo usando el software NOBO
2024-04-04 Update circuito .md
2024-06-09 Delete dattaloger control.jpg
    x pedido de Lucas
2024-06-09 Delete README.md
    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
2024-06-09 Delete dispositivo con display oled v02.png
    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
2024-06-09 Delete el biologo y la mosca y la rampa de la muerte.jpg
    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
2024-06-09 Delete el biologo y la mosca.jpg
    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
2024-06-09 Delete mosca suzukee.jpg
    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
